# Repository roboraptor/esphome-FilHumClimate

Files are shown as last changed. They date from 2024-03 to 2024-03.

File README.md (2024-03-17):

# ESPHome Filament Dryer Humidity Climate control
<p align="center">
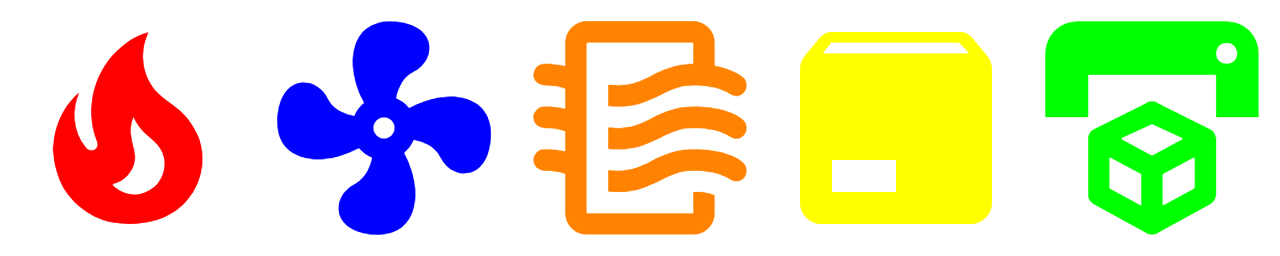
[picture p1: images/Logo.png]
  
</p>

### Welcome to my project 
ESPHome Climate Thermostat controller made for DIY filament dehumidifier with swiched heat element and fan.  
(For now, switching between climate modes and temperature control is done by HomeAssistant. )

#### Used Hardware:
- ESP 8266
- DHT22 Temperature & Humidity Sensor
- SH1106 96x16 I2C Display
- WS2812 Addressable LEDs
- Smart Switchable Electric Socket (Relays) 
- Air Food Dehydratator (part with fan and heating element)

I implemented second DHT22 sensor just for logging purposes and future corrections according to possible box sizes.

#### Temperature and Humidity of both sensors should be seen on SH1106 96x16 I2C Display  

| Temp1 | Hum1 |
| ----- | ---- |
| Temp2 | Hum2 |

(Thinking about adding climate state too, but the display is too small)

#### Climate presets and the whistles
| Name | Mode | Target | TopRightIcon | LED Effect |
| --- | --- | --- | --- | --- |
| Dry | HEAT | 45°C-50°C | D | Red Pulsing |
| Cool-FO | FAN_ONLY | 15°C-35°C | F | Azure |
| Cool | COOL | 15°C-35°C | C | Blue |
| Idle | OFF | 10°C-25°C | O | Rainbow |

(I want to play with more with cool and fan_only difference and see in future what is better)

Target Humidity should be below 10%.
If reached, climate control is automatically set to cool-fo but there should be some more decidement on previous state of climate control or something.

This whole thing has 2 outputs, for fan and heater.  
It is supposed to control relays and switch Fan and Heating element in Air Food Dehydratator.  
**Working with devices that use high voltage is _dangerous._**  
Please consider your safety, knowledge and skills.  
***Do it only at your own risk.***  

Here is few pictures 

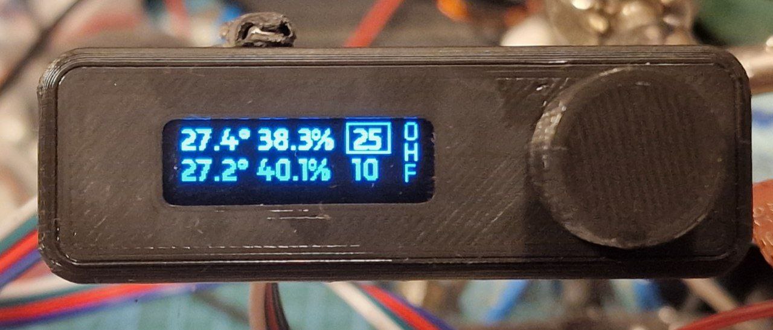
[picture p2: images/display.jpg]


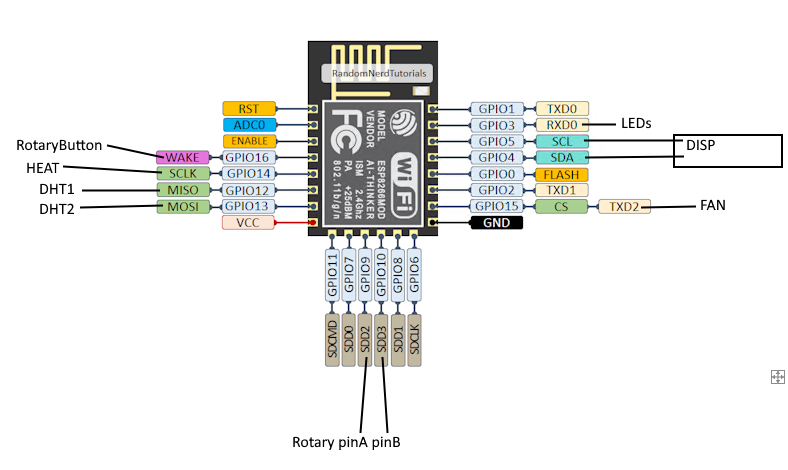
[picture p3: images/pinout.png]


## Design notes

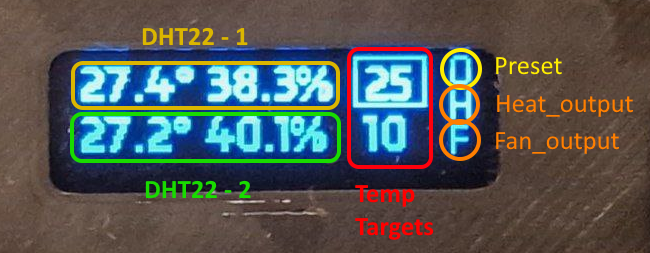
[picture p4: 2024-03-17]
images/display_explained.png

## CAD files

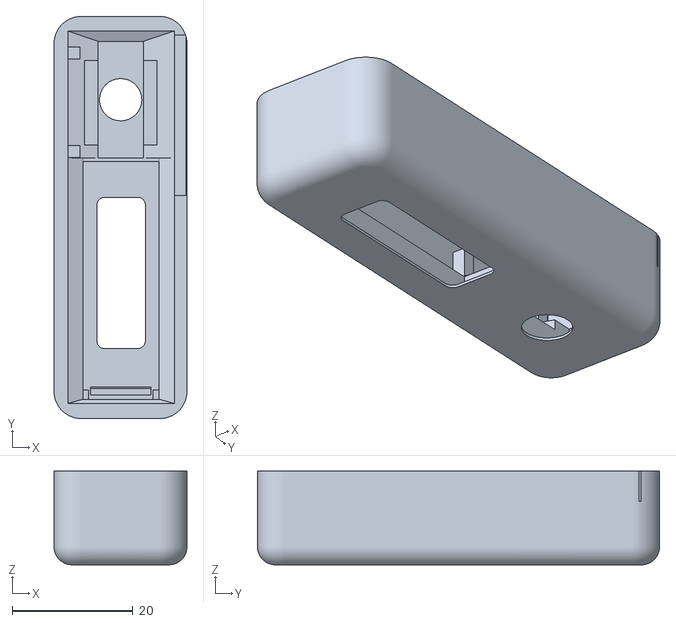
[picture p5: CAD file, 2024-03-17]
3d/untitled-OLED_bezel2.stl
22.0 x 66.5 x 15.5

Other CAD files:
3d/untitled1-OLED_bezel2.stl
3d/untitled1-OLED_bezel1.stl
3d/untitled1.blend

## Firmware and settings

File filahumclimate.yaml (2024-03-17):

substitutions:
  sda_pin: GPIO4 # ESP8266 SDA pin
  scl_pin: GPIO5 # ESP8266 SCL pin
  dht1_pin: GPIO12 # First DHT22 pin
  dht2_pin: GPIO13 # Second DHT22 pin
  heat_pin: GPIO14 # Heater Relay pin
  fan_pin: GPIO15 # Fan Relay pin
  led_pin: GPIO3 # Addressable LED pin (WS2812) / wled supports GPIO2
  but_pin: GPIO16 # Rotary Encoder Button
  rea_pin: GPIO9 # Rotary Encoder pin A
  reb_pin: GPIO10 # Rotary Encoder pin B

esphome:
  name: filahumclimate
  friendly_name: FilaHumClimate

esp8266:
  board: esp01_1m

# Enable logging
logger:

# Enable Home Assistant API
api:
  encryption:
    key: <YOUR_ENCRIPTION_KEY>

ota:
  password: <YOUR_OTA_PASS>

wifi:
  ssid: !secret wifi_ssid
  password: !secret wifi_password

  # Enable fallback hotspot (captive portal) in case wifi connection fails
  ap:
    ssid: "Filahumclimate Fallback Hotspot"
    password: <YOUR_AP_PASS>

captive_portal:
    
i2c:
  sda: $sda_pin
  scl: $scl_pin
  scan: true

font:
  - file:
      type: gfonts
      family: "Madimi One"
    id: my_font
    size: 15
  - file:
      type: gfonts
      family: "Roboto"
      weight: 100
    id: my_font2
    size: 12


sensor:
  - platform: dht
    pin: $dht1_pin
    model: AM2302
    temperature:
      name: "Filament Temperature 1"
      id: fil_tmp_1
    humidity:
      name: "Filament Humidity 1"
      id: fil_hum_1
      accuracy_decimals: 1
      on_value_range:
        - below: 10
          then:
            - light.turn_on:
                id: leds
                brightness: 50%
                effect: "Fireworks"
    update_interval: 5s
    
  - platform: dht
    pin: $dht2_pin
    model: AM2302
    temperature:
      name: "Filament Temperature 2"
      id: fil_tmp_2
    humidity:
      name: "Filament Humidity 2"
      id: fil_hum_2
      accuracy_decimals: 1
    update_interval: 5s

  - platform: rotary_encoder
    id: encoder
    pin_a:
      number: $rea_pin
      mode: INPUT_PULLUP
    pin_b:
      number: $reb_pin
      mode: INPUT_PULLUP
    on_clockwise:
        - if:
            condition:
              switch.is_on: heat_cool
            then:
              - climate.control:
                  id: therm
                  target_temperature_high: !lambda "return id(therm).target_temperature_high + 1;"
            else:
              - climate.control:
                  id: therm
                  target_temperature_low: !lambda "return id(therm).target_temperature_low + 1;"

    on_anticlockwise:
      then:
        - if:
            condition:
              switch.is_on: heat_cool
            then:
              - climate.control:
                  id: therm
                  target_temperature_high: !lambda "return id(therm).target_temperature_high - 1;"
            else:
              - climate.control:
                  id: therm
                  target_temperature_low: !lambda "return id(therm).target_temperature_low - 1;"

switch:
  - platform: gpio
    name: "Heating"
    id: "heat_state"
    pin: $heat_pin
    inverted: false
  - platform: gpio
    name: "Fan"
    id: "fan_state"
    pin: $fan_pin
    inverted: false
  - platform: template
    id: heat_cool
    optimistic: true

binary_sensor:
  - platform: gpio
    id: button
    pin:
      number: $but_pin
      inverted: true
    on_press:
      then:
        - switch.toggle: heat_cool
    on_click:
      - min_length: 1000ms
        max_length: 20000ms
        then:
          - select.operation:
              id: therm_pre
              operation: Next
              cycle: true
          - if:
              condition:
                - lambda: 'return id(therm_pre).state == "off";'
              then:
                - climate.control:
                    id: therm
                    custom_preset: Idle
          - if:
              condition:
                - lambda: 'return id(therm_pre).state == "dry";'
              then:
                - climate.control:
                    id: therm
                    custom_preset: Dry
          - if:
              condition:
                - lambda: 'return id(therm_pre).state == "coolfan";'
              then:
                - climate.control:
                    id: therm
                    custom_preset: Cool-FO
          - if:
              condition:
                - lambda: 'return id(therm_pre).state == "cool";'
              then:
                - climate.control:
                    id: therm
                    custom_preset: Cool                                                            

select:
  - platform: template 
    name: "Climate presets"
    id: therm_pre
    options:
     - "off"
     - "dry"
     - "coolfan"
     - "cool"
    initial_option: "off"
    optimistic: true
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

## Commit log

2024-03-14 Create filahumsensor.yaml
    Only sensors with display
2024-03-15 Update filahumclimate.yaml
    Added rotary encoder for setting up temperature and switching presets.
2024-03-15 Update filahumclimate.yaml
    Fixed build errors
    [filahumclimate.yaml]
